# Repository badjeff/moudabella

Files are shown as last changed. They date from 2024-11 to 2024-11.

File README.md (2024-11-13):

# moudabella

An open source bluetooth mouse 🐭 for CAD 🐱.

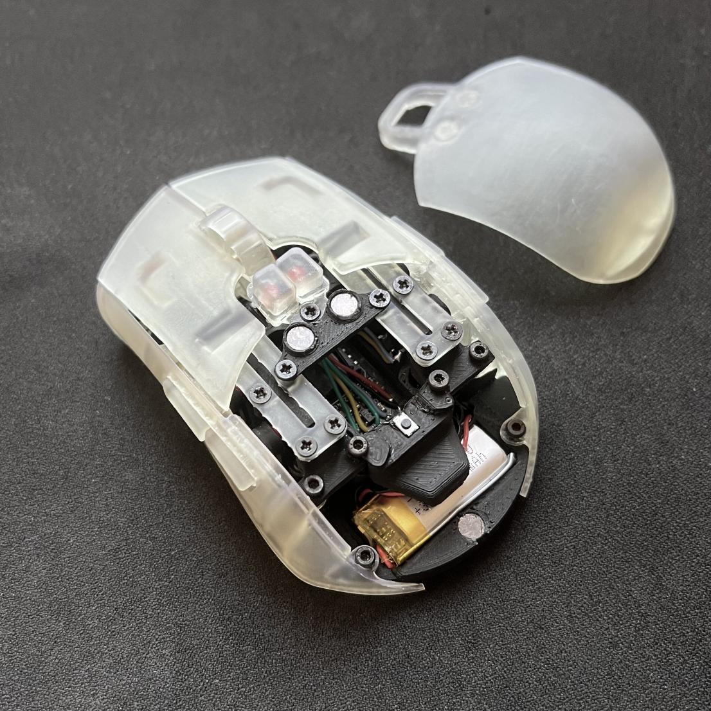
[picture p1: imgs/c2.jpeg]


*Figure 1: PLA base / Resin shell

### Design Principles
- Symmetrical design
- 9 buttons
- Y2K Macintosh vibe
- No visible screws
- Not-too-bad middle click and scrolling
- Adjustable sensor position. With my slim breakout pcb. https://github.com/badjeff/pmw3610-pcb
- Powered by [ZMK](https://github.com/zmkfirmware/zmk) => OSS, on-devie profiling, say no to (Logxtxxh|Razxx) eco-system
- Optimized for fingertip grip and claw grip, swapable part for palm grip
- Easy facelifting. (and reprinting the yellowish parts)
- Ligthweight
- Medium to small size
- Rigid
- Long battery life
- Silent tactile switches
- Low Profile

### Gallery

[🎥 Sound Test](https://imgur.com/a/Uihee3r)

<p float="left">

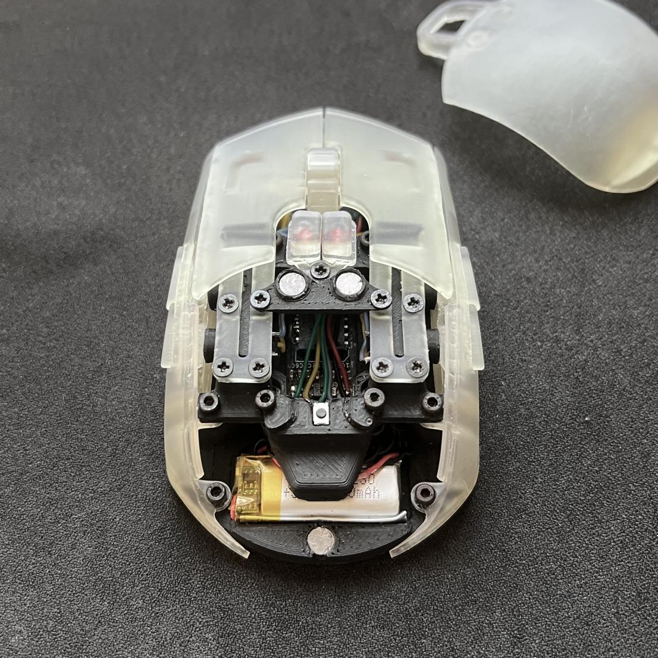
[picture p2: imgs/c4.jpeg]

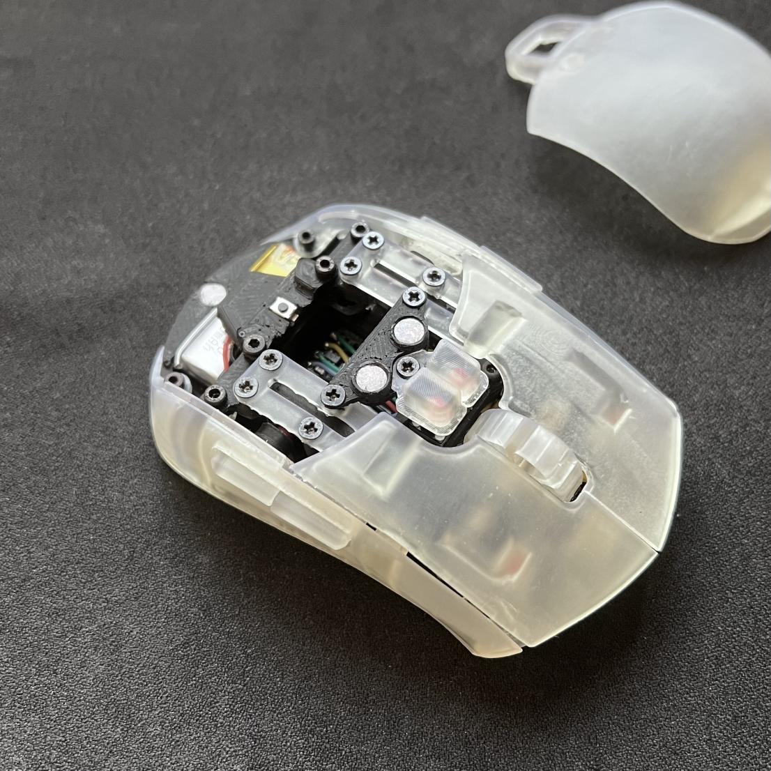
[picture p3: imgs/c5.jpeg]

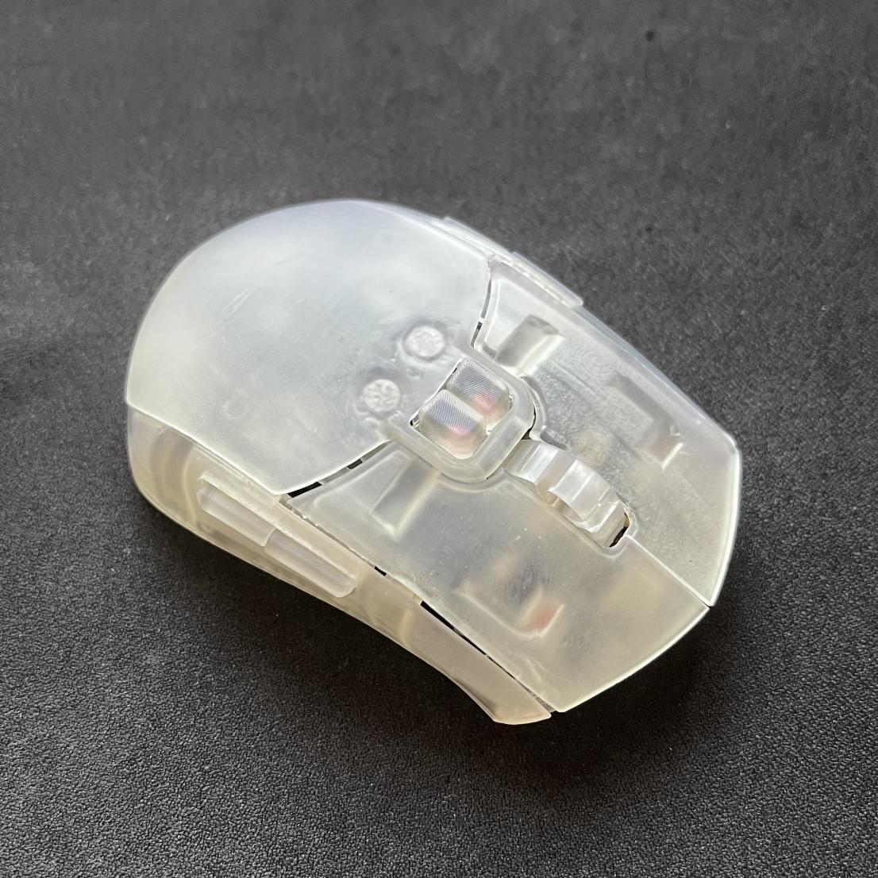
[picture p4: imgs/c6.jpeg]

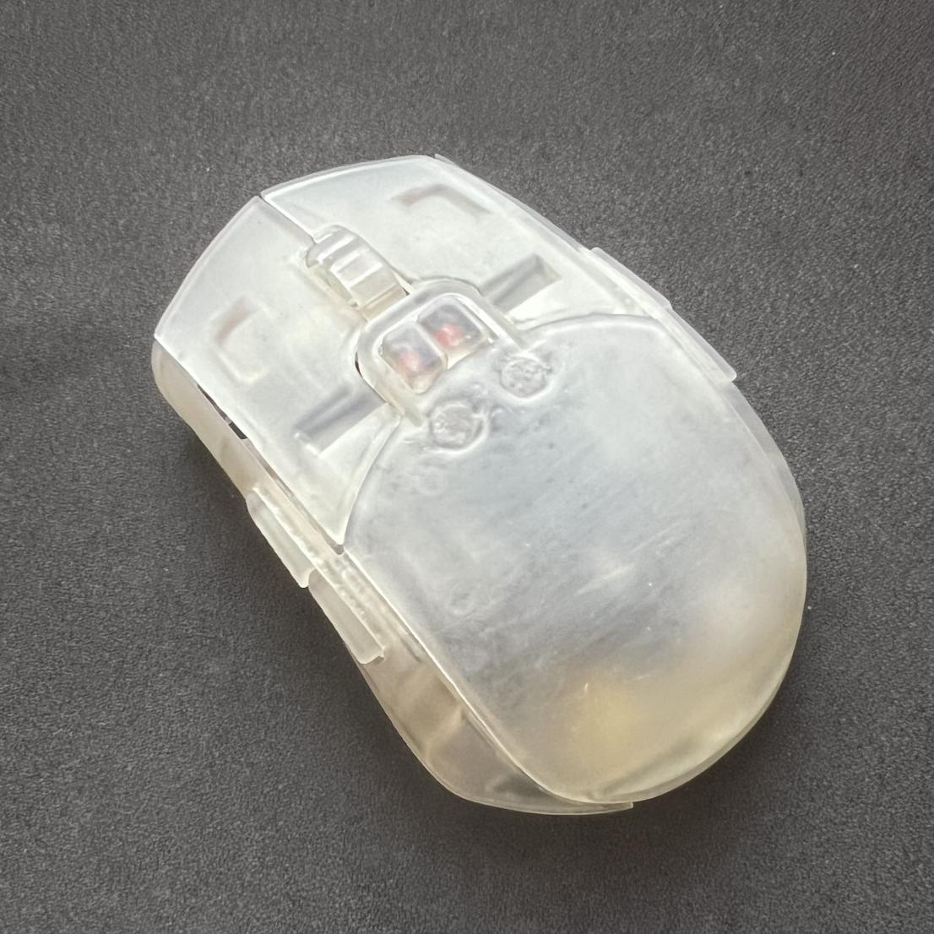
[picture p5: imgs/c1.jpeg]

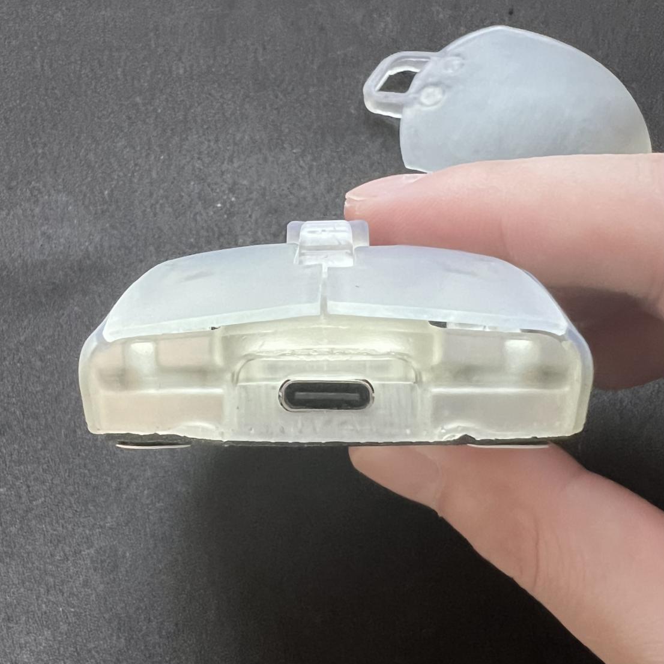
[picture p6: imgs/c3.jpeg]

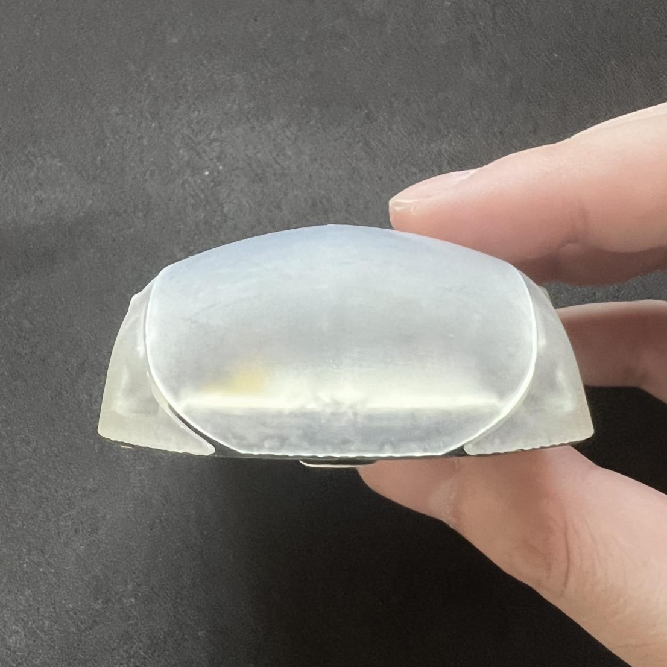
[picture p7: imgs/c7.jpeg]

</p>

### BOM
|Unit|Item|
|-|-|
|1|Seeed Studio XIAO BLE (nRF52840)|
|1|PWM3610 Sensor [Breakout Board](https://github.com/badjeff/pmw3610-pcb)|
|9|Kailh CMI627301D07 6x6x7.3mm Silent Micro Switch|
|9|1N4148W T4 SOD-123 Diode|
|1|ALPS EC05-E1220401 (Vertical) Rotary Encoder|
|1|MSK-1153 6 Pins Power Switch|
|1|3x4x2mm Tact Switch Turtle Switch|
|1|M2 Screw Boxset (3-10mm)|
|6|Neodymium Disc Magnets 5x1mm (Diameter x Thick)|
|1|601230 Lipo Battery (plus connector)|
|5|Thick Mouse Feet Skates Dots (~0.7mm)|
|1|28/26 AWG silicone wire|
|1|For FDM printing, 30x2mm Metal Shaft (File one end into a hexagonal shape, fit in EC05 Rotary Encoder)|

### Building Guide / Tips

- Print base plate with PLA, easier to screw
- Use double-sided tap to secure the sensor breakout PCB while no futher position adjustment needed
- Lens-to-Surface distance must >2.4mm & <2.9mm. Mouse Feet must >0.65mm.
- Scroll wheel tube diameter is 2.2mm. Wrapping metal shaft with taps to fit, superglue one end if fitting done.

### Firmware

The ZMK firmware config repository can be find at [badjeff/moudabella-zmk-config](https://github.com/badjeff/moudabella-zmk-config).

## License

Available under the [CERN-OHL-P v2](/LICENSE) permissive license.

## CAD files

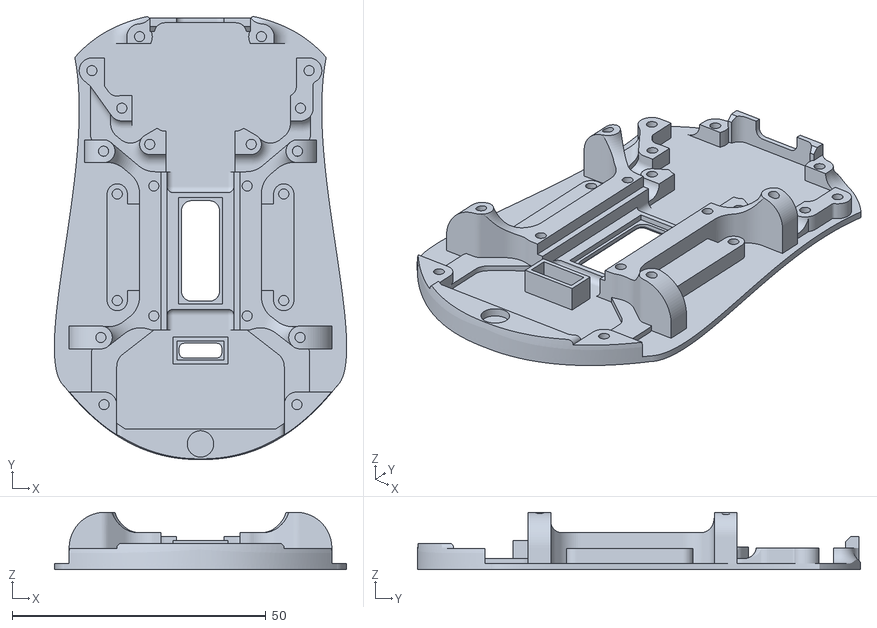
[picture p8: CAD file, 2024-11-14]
STLs/a1 - base.stl
57.6 x 87.3 x 11.3

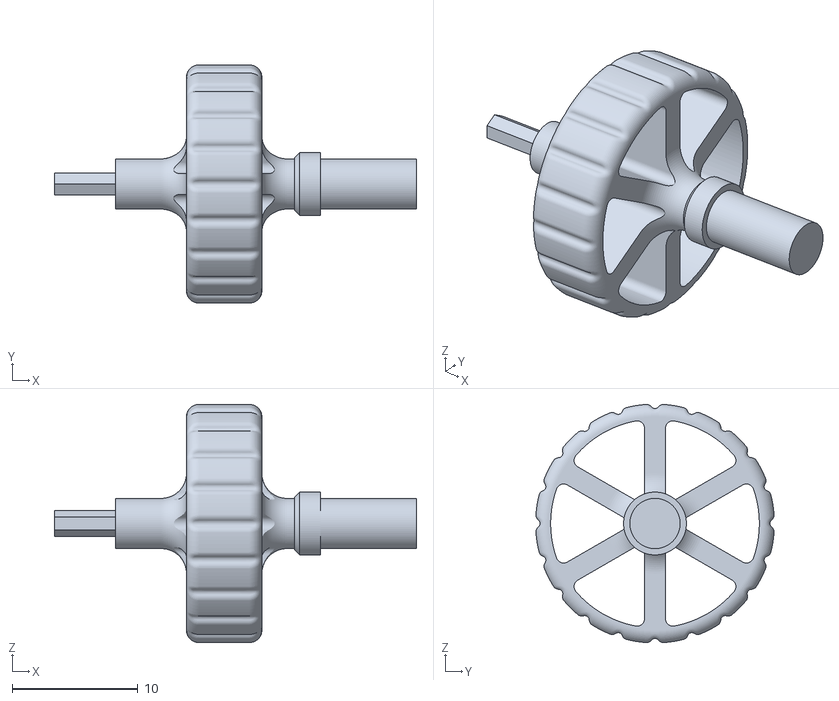
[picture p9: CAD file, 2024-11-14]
STLs/a5 - wheel shaft.stl
28.8 x 18.9 x 18.9

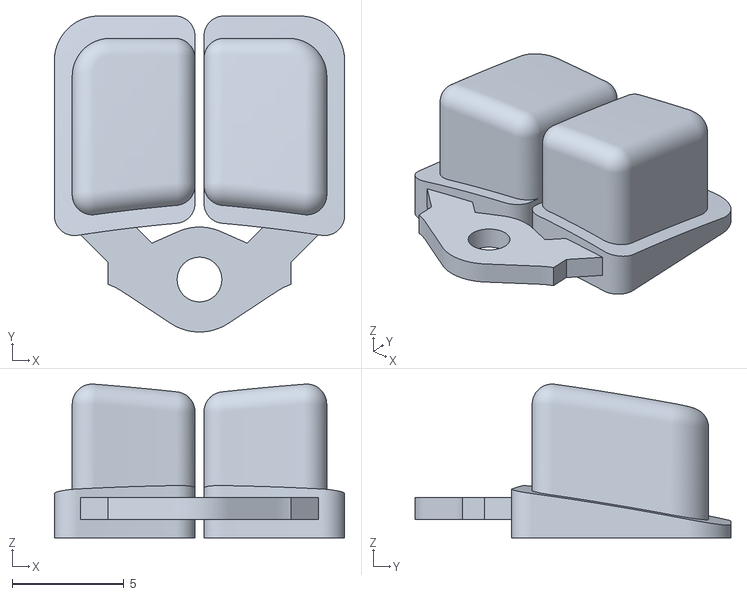
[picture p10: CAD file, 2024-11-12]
STLs/e4 - peak buttons.stl
13.0 x 14.2 x 6.89

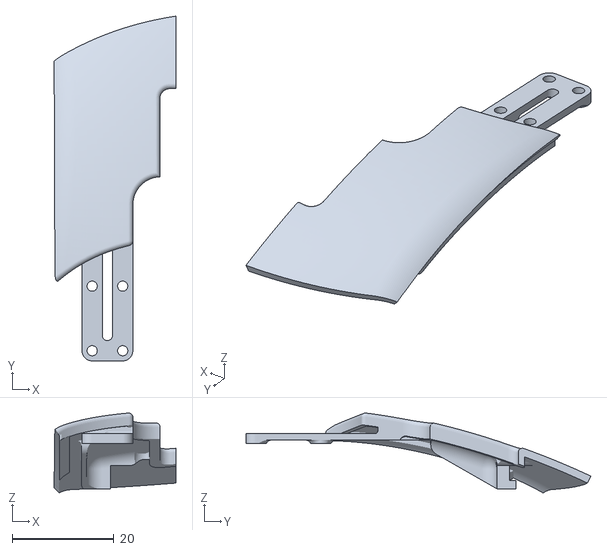
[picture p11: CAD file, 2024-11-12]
STLs/e1 - left click.stl
24.0 x 67.8 x 15.7

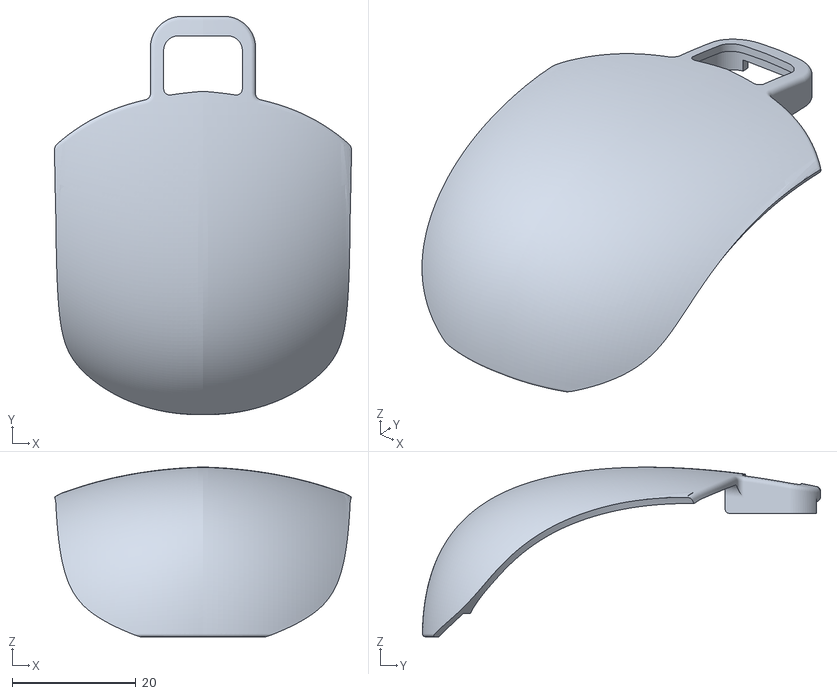
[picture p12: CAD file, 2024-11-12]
STLs/e5 - rear cover.stl
48.0 x 64.3 x 27.4

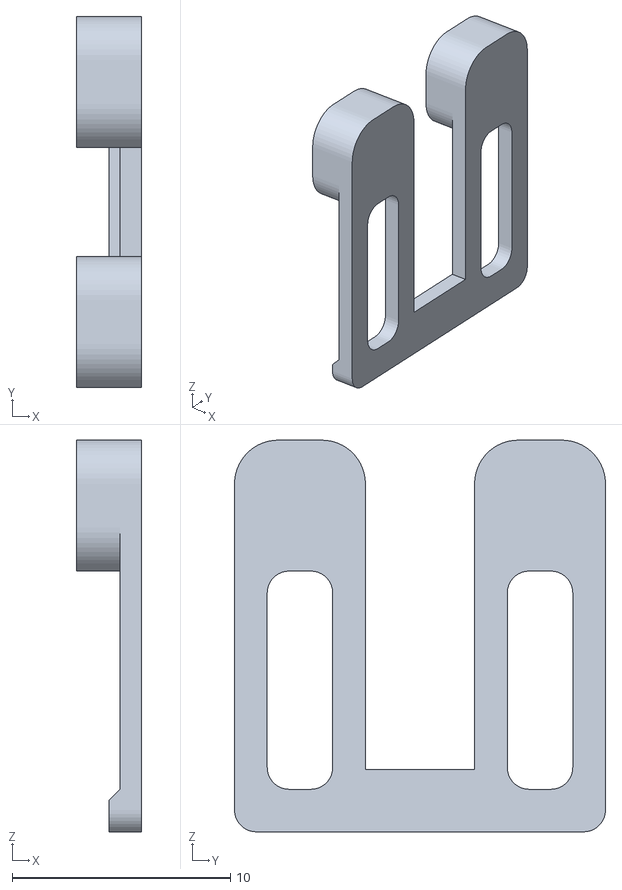
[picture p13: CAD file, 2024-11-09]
STLs/b1 - side arms L.stl
3.00 x 17.0 x 17.9

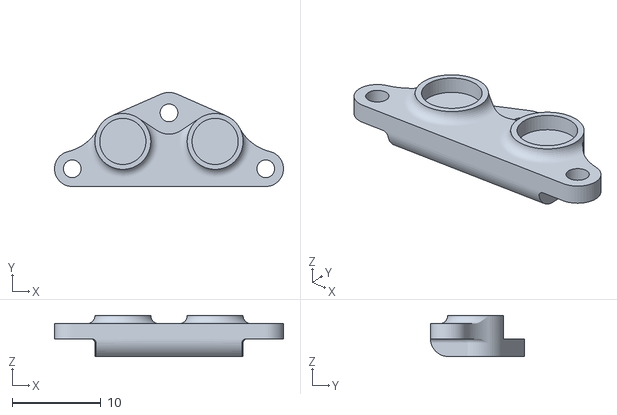
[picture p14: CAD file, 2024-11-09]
STLs/e3 - centric top mount.stl
25.8 x 10.6 x 4.62

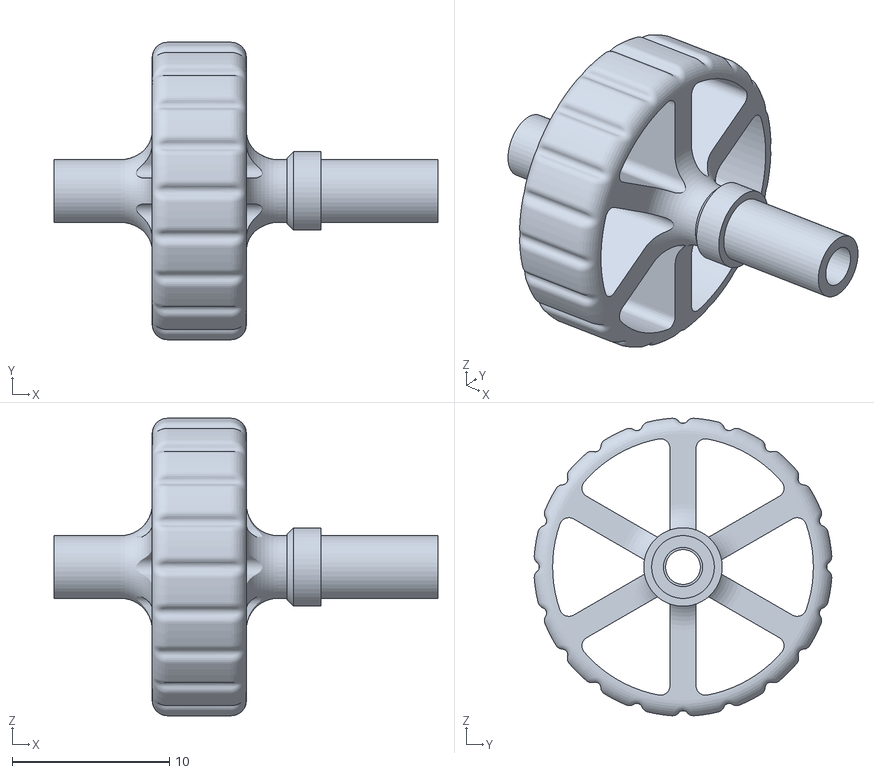
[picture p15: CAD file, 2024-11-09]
STLs/a5 - wheel.stl
24.4 x 18.9 x 18.9

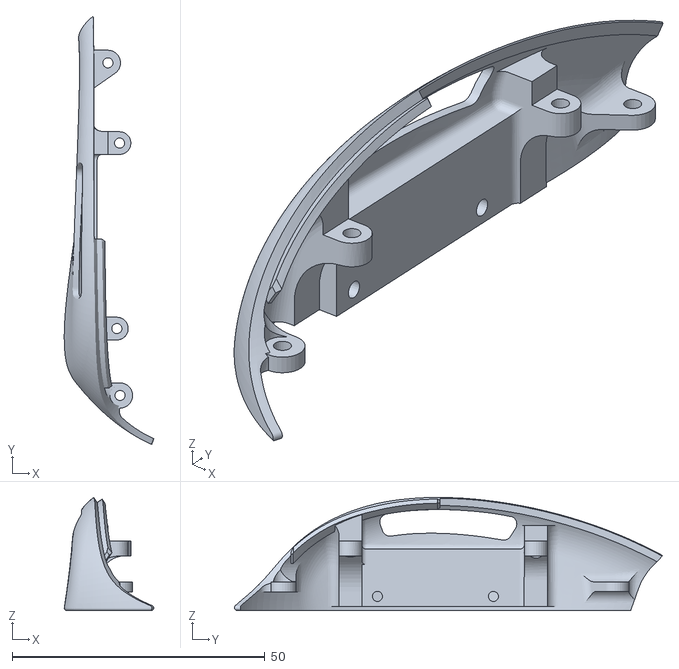
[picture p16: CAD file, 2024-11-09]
STLs/d1 - side left.stl
17.7 x 84.7 x 22.4

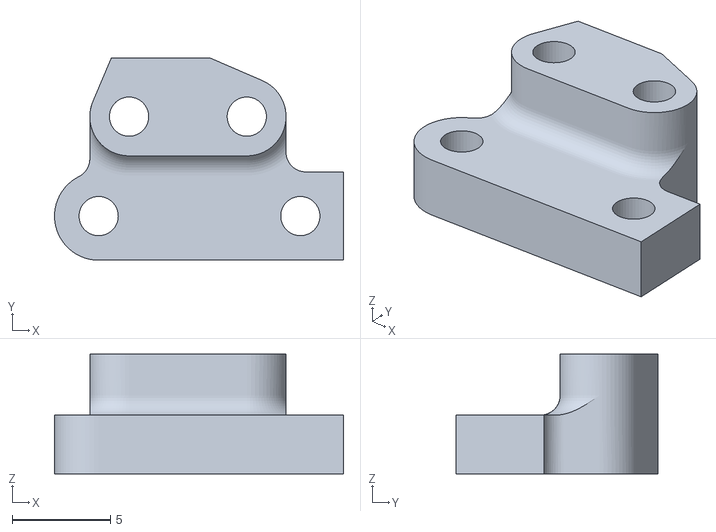
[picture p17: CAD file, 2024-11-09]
STLs/c5 - roll bar R.stl
14.7 x 10.3 x 6.09

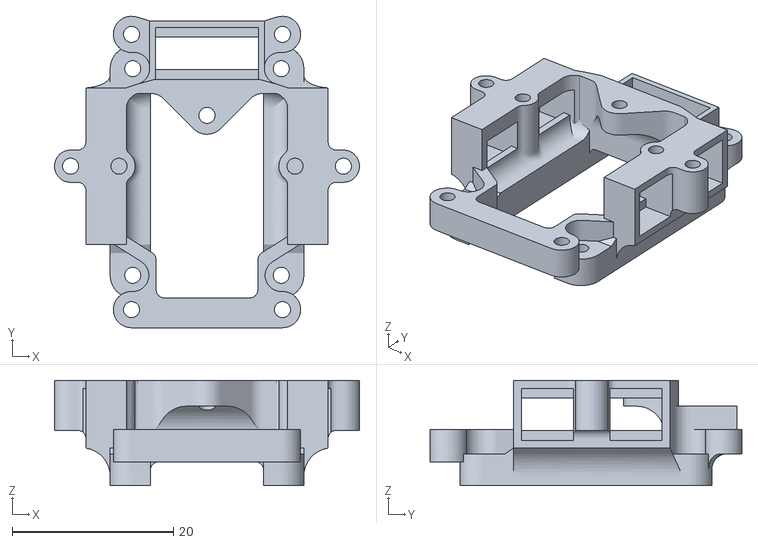
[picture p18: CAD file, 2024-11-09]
STLs/a6 - centric standoff.stl
37.8 x 38.6 x 13.1

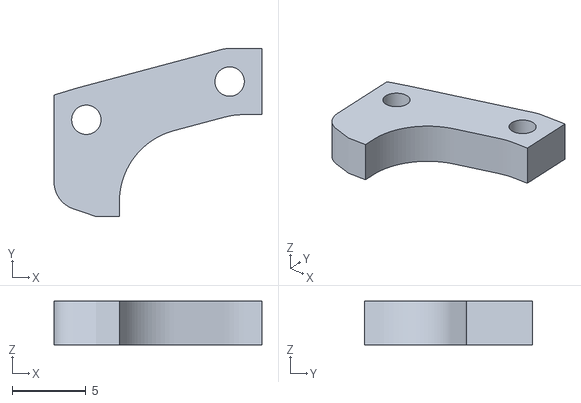
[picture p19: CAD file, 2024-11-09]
STLs/c2 - collar right.stl
14.1 x 11.4 x 2.99

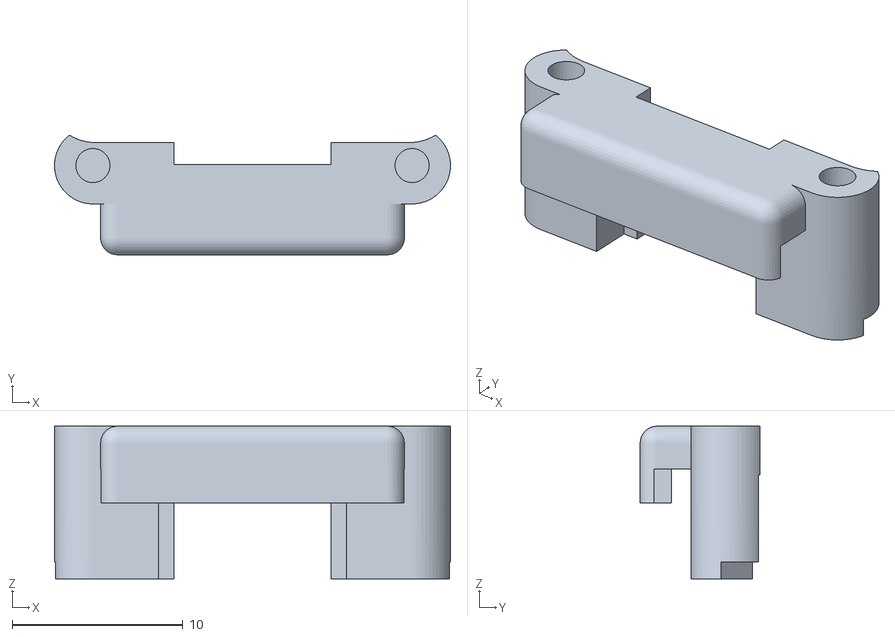
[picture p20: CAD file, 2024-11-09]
STLs/c3 - power switch cover.stl
23.2 x 7.01 x 8.95

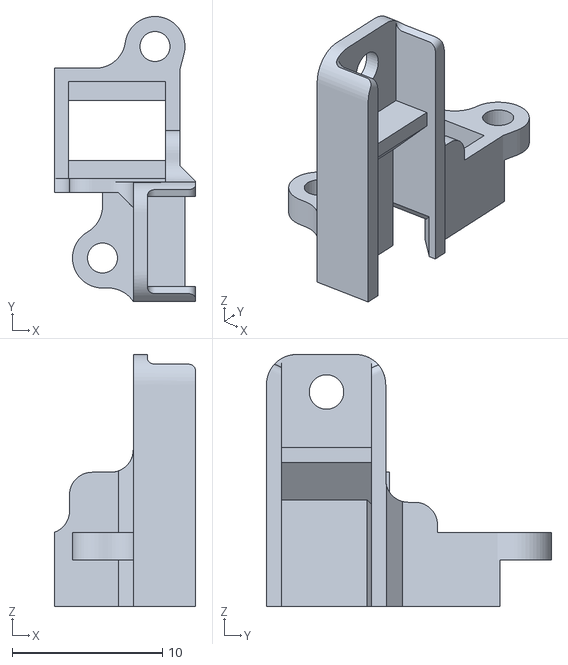
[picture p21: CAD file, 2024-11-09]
STLs/a2 - L btn mount.stl
9.40 x 19.0 x 16.8

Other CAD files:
STLs/e2 - right click.stl
STLs/b3 - side arms R.stl
STLs/c4 - roll bar L.stl
STLs/d3 - side right.stl
STLs/a3 - R btn mount.stl
STLs/a4 - mcu clip.stl
STLs/a7 - shell front.stl
STLs/b2 - side arms clip L.stl
STLs/b4 - side arms clip R.stl
STLs/c1 - collar left.stl
STLs/c6 - battery cover.stl
STLs/d2 - side buttons left.stl
STLs/d4 - side buttons right.stl

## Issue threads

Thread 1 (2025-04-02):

Palm grip rear cover

violet-fish, 2025-04-02:
In the readme, you mention a swappable part for palm grip, but I do not see a file for this part. Is this something you are planning on adding in the future or is more so an option if someone wanted to adjust the design to add this feature?

badjeff, 2025-04-02:
Sorry for the confusion. That is planned, but I don't have time to CAD one yet.

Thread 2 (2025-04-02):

Wiring diagram

violet-fish, 2025-04-02:
I was mostly able to follow the pinout in the zmk config, but I did not see any pinout or wiring diagram. I can most likely reverse engineer the zmk config, but having guidance would make the process much easier.

badjeff, 2025-04-02:
I handwired a 3x3 matrix, and **twist & fold** the first column (switch-0-3-6) at 90 degree for L/M/R mouse button.

You might be find easiler to see the matrix with comments in below.
```
// moudabella.dtsi:
positions
  //(COL1)--------(COL2)---(COL3)
  // D0            D1.      D2
  // P0.2          P0.3     P0.28
  = < 0             1        2  >  // D3 P0.29 (ROW 1)
  , < 3             4        5  >  // D4 P0.4  (ROW 2)
  , < 6             7        8  >  // D5 P0.5  (ROW 3)
;

// moudabella.keymap
// Keys projection from TOP view
   0   3   6   <-- physical layout of L/M/R mouse button key *** THIS IS COL1 ***
     1   2     <-- shoulder twins key
   4       5   <-- the side buttons
   7       8
```

I did wire the (yellow) cols first and connect the (blue) rows after putting all switches in place.
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

The switches were all pre-dioded like this.
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

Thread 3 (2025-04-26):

Challenges and hurdles

ChrisCross3, 2025-04-26:
Hello there,

Please excuse me for trying to establish contact this way.

I would like to use ZMK to create my own mouse too and would love to discuss challenges and hurdles with you.

Regards,
Chris

badjeff, 2025-04-27:
Please tell your concern on ZMK Discuss Server. Many people can help too.
https://zmk.dev/community/discord/invite

ChrisCross3, 2025-04-27:
Will do. 🙂
Thank you. 🙏

Closed 2025-04-27.

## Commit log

2024-11-11 add reinforcement on the click button
    [e1 - left click.stl, e2 - right click.stl]
2024-11-12 adjust tolerance for resin printing
    [a5 - wheel shaft.stl, e1 - left click.stl, e2 - right click.stl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]
2024-11-14 adjust wheel shaft margin
    [a5 - wheel shaft.stl]
2024-11-14 adj. the margin on front of base plate
    [a1 - base.stl]
2024-11-19 add CAD files
